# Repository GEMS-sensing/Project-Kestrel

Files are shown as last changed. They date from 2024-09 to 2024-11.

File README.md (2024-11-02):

<!-- [![DOI](https://zenodo.org/badge/678911830.svg)](https://zenodo.org/doi/10.5281/zenodo.13377368) -->

# Project-Kestrel
Core board for a Flight data logger, featuring interfaces to Talon boards ([SDI-12 Talon](https://github.com/GEMS-sensing/Talon-SDI12), [I2C Talon](https://github.com/GEMS-sensing/Talon-I2C), [Auxiliary Talon](https://github.com/GEMS-sensing/Talon-Auxiliary)) and external battery board ([Gonk](https://github.com/GEMS-sensing/Project-Gonk)). This is the core component of [Flight data logger](https://github.com/GEMS-sensing/DFM_-_Flight?tab=readme-ov-file).

# Repo Roadmap
#### [Documents](Documentation/) 

General document and image storage for repo and README

#### [Hardware](Hardware/)

Current board files (Eagle), Bill of Materials (BoM), and other design documents

#### [Production](Production/)

Contains the various Gerber and pick and place files required to have the Printed Circuit Boards (PCBs) manufactured or populated 

#### [Software](Software/)

The software associated with the piece of hardware, this is usually diagnostic software used for verifying or investigating the hardware

<!-- #### [Mechanical](Mechanical/)

Mechanical design files and assembly documents -->

<!-- #### [Testing](Testing/)

Scripts and results from the testing process and development process. Contains more detailed information about documented issues among other testing. 
 -->

## Overview
* **Type:** Logger
* **Interfaces:** Talon, Gonk
* **Release Version:** v1.9 - 2023/06/23

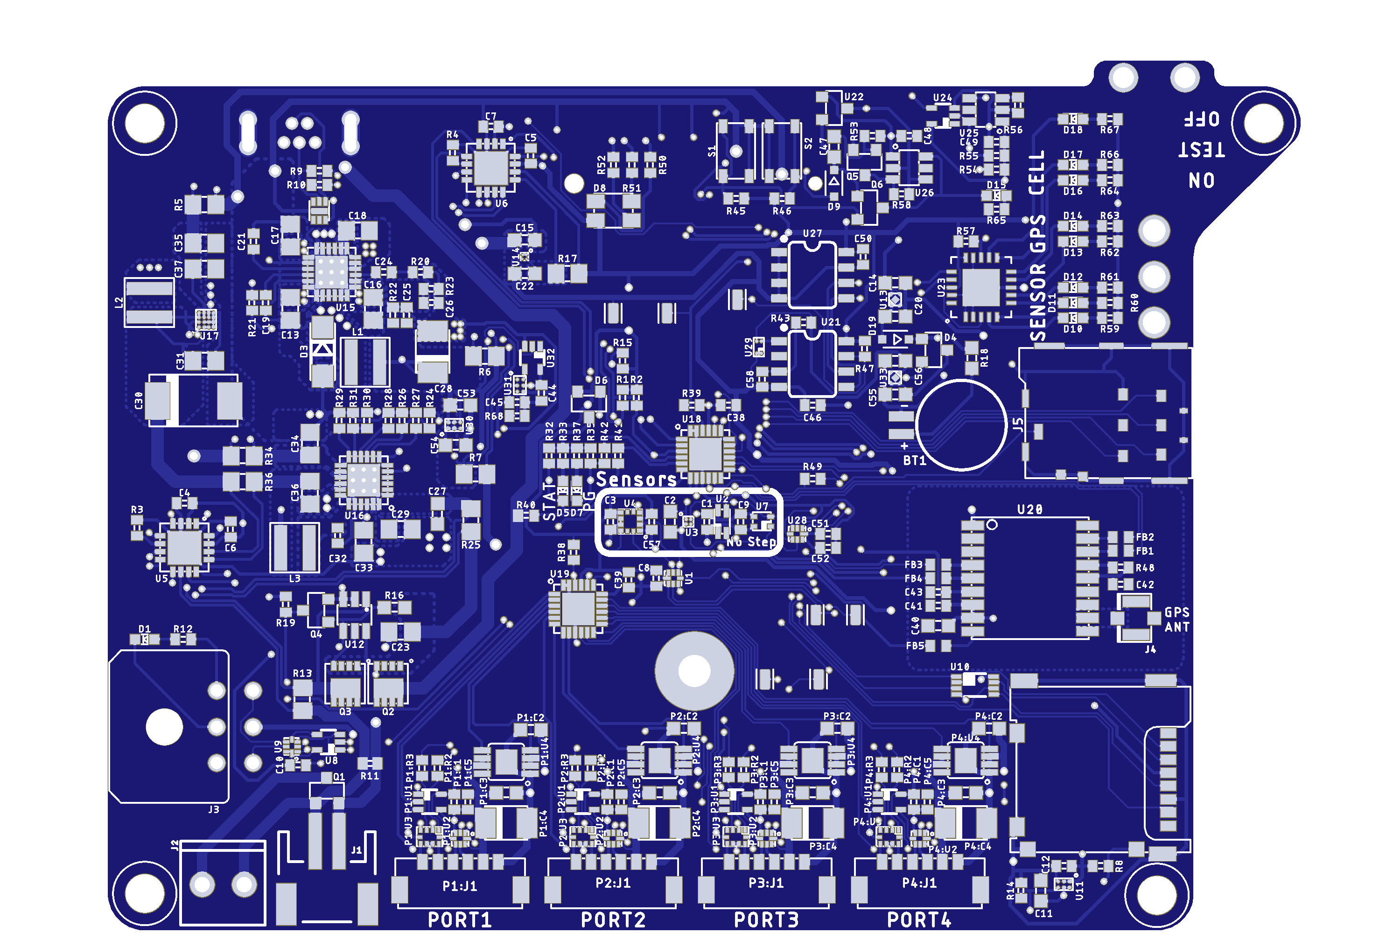
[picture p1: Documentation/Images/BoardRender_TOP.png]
PCB render image, top


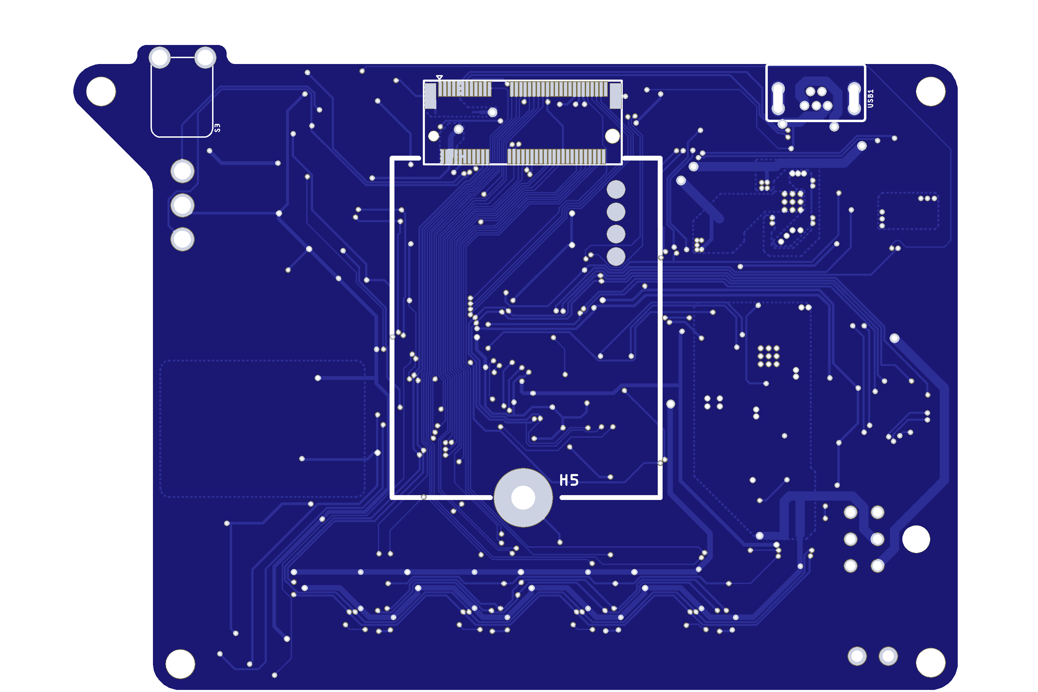
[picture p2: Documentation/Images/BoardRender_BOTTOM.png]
PCB render image, bottom


<!-- ![Haar v0.0 - Bottom](Documents/Images/Haar_0v0_Bottom_Cropped.jpg) -->

## Features
### On-Board
* Modular interfaces for Talon daughterboards (x4)
	* Isolated I2C interface
	* Individual power control and monitoring
	* Firmware selectable GPIO/UART interface
	* Polarized connector
* Battery board interface 
	* I2C interface for battery power reporting
	* Polarized connector
* Multi-charger input
	* Solar panel (6V) input
	* High power (>2A) input for fast charge in no solar situations
* [Particle BSoM](https://docs.particle.io/b-series/) M.2 interface
	* Interface for the highly flexible Particle BSoM module
* Micro USB interface 
	* Programming and charging
* Power switch
	* Complete disconnect 
	* Tri position to allow for 'ON'-'TESTING'-'OFF' modes
* LED status indicators 
* Non-Contact safe mode circuit 
	* Safe mode circuit controlled by Hall effect sensor to allow for triggering with magnet from outside logger box
* Multi-rail power system
	* Allow for independent control of subsystems, on-board and off-board
* On-board GPS Module with battery backup for improved hot start
* SD Card interface
* On-board sensing for self diagnostics
	* Voltage/current sensing (8 positions)
	* Temperature
	* Humidity
	* Accelerometer, 3 axis
	* Magnatometer, 3 axis
	* Ambient light, multi channel
* Interchangeable SIM card (future support)
* RTC with rechargeable battery backup
* FRAM storage for low power backhaul batching
* Long period WatchDog control to prevent critical lockups 

<!-- ### Interface
* I<sup>2</sup>C
* M12 circular connector  -->

<!-- <picture>
  <source media="(prefers-color-scheme: dark)" srcset="Documents/Pinout_LIGHT.png">
  <img alt="Haar Connector Pinout" src="Documents/Pinout.png">
</picture> -->

<!-- ## Specifications
* **Voltage - Supply:** 3.3V
* **Voltage - Logic:** 3.3V
* **Input Current (Avg, 1s period): 30.95&mu;A @ 3.3V**
* **Input Current (Avg, 5s period): 107.43&mu;A @ 3.3V**
* **Input Current (Max): 0.45mA @ 3.3V**

#### Sensor
**Temperature** [^1]
* Range: -40 ~ 125°C 
* Accuracy: &plusmn; 0.2°C
* Repeatability: &plusmn; 0.04°C

**Pressure** [^2]
* Range: 300 ~ 1200 hPa  
* Accuracy: &plusmn; 1 hPa
* Repeatability: &plusmn; 0.06 hPa

**Humidity** [^1]
* Range: 0 ~ 100%
* Accuracy: &plusmn; 2%
* Repeatability: 0.08%

[^1]: [SHT31 Datasheet](https://sensirion.com/media/documents/213E6A3B/63A5A569/Datasheet_SHT3x_DIS.pdf)
[^2]: [DPS368 Datasheet](https://www.infineon.com/dgdl/Infineon-DPS368-DS-v01_00-EN.pdf?fileId=5546d46269e1c019016a0c45105d4b40) -->

<!-- ## Version History

`v0.0` - Initial primal version with screw terminal

`v0.1` - Initial 'hard mount' version, using M12 connector

`v1.0` - Removed pullup select[^3], added logic level buffer and voltage reg on input

`v1.1` - Moved via away from connector pads to prevent bridging when soldering 

`v2.0` - Fixed issue with address select jumper[^3] -->

<!-- ## Jumper Settings 

> [!IMPORTANT]
> Jumper settings valid for version `v2.0` and beyond[^3]

[^3]: See Errata

**Configuration Jumpers**
| Jumper | Purpose | Open | Closed | Default | 
| --- | --- | --- | --- | ----- |
| `JP1` | I<sup>2</sup>C Address Select | Base Address<sup>&dagger;</sup> | Alt Address<sup>&Dagger;</sup> | Open |

&dagger; SHT31 = `0x44`, DPS368 = `0x76`

&Dagger; SHT31 = `0x44`, DPS368 = `0x77`

 -->

## Version History

v1.7 updates:
- Connected DONE line on U26 to ensure consistent trip (prevent factory reset while using hall effect control)
- Changed label for 'STAT' led in upper right corner to 'SYS', this was done to reflect the current usage of the indicator and to eliminate confusion between this indicator and the indicator lamp for the battery charge (also labeled 'STAT')
- Switched amber LEDs to yellow

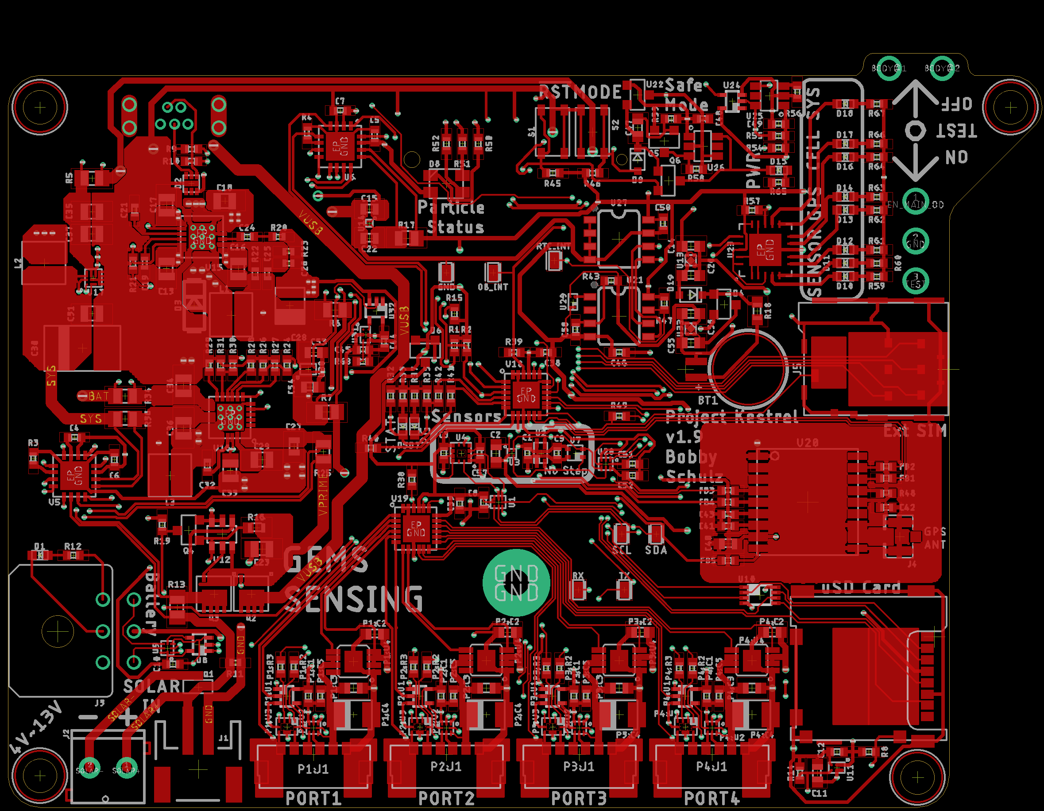
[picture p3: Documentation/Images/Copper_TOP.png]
PCB trace CAD image, top


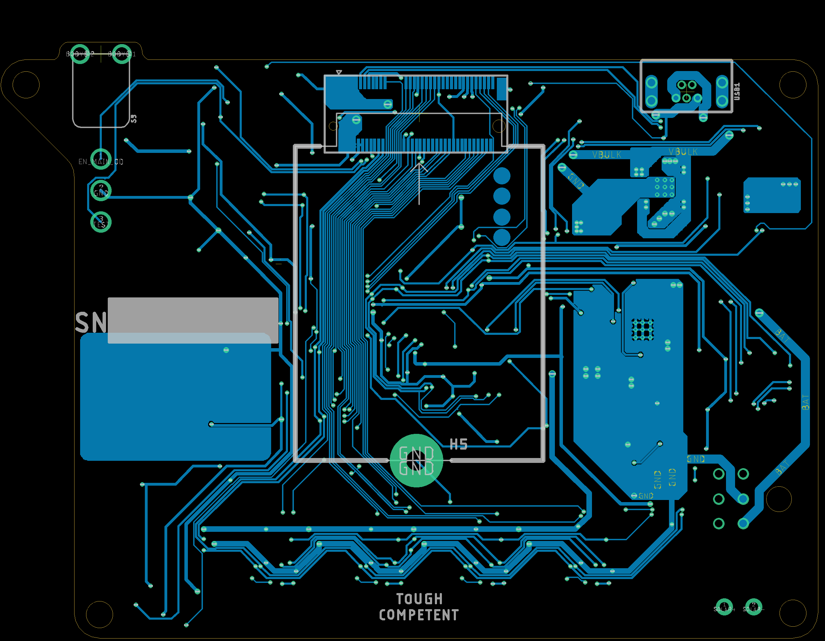
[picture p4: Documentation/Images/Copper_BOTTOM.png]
PCB trace CAD, bottom


## Known Issues/Errata

#### Solder Jumper Stencil

**Version Affected:** All

**Issue:** Solar input does not support very low impedance sources (e.g. lead acid battery) - see details in issue [#20](https://github.com/GEMS-sensing/Project-Kestrel/issues/20)

**Workaround:** 

* Avoid use of low impedance batteries for input
* Include series impedance to prevent current spikes (not desirable)
* Perform board patch described in issue [#20](https://github.com/GEMS-sensing/Project-Kestrel/issues/20)

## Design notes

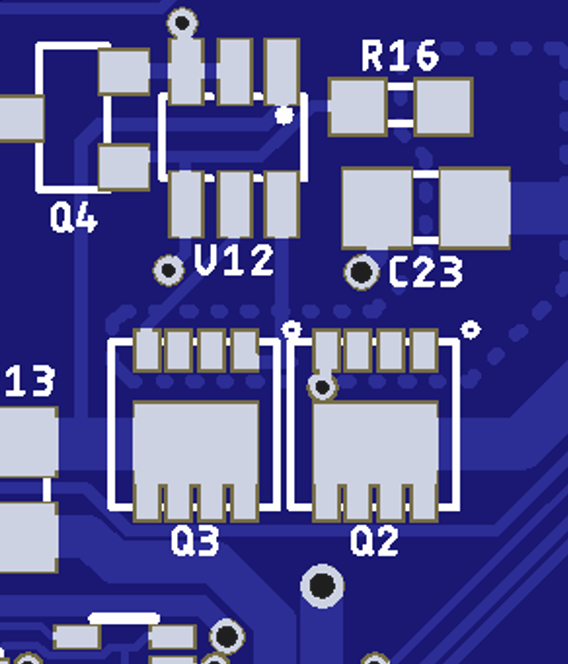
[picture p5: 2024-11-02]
Documentation/Images/Q2Subset.png

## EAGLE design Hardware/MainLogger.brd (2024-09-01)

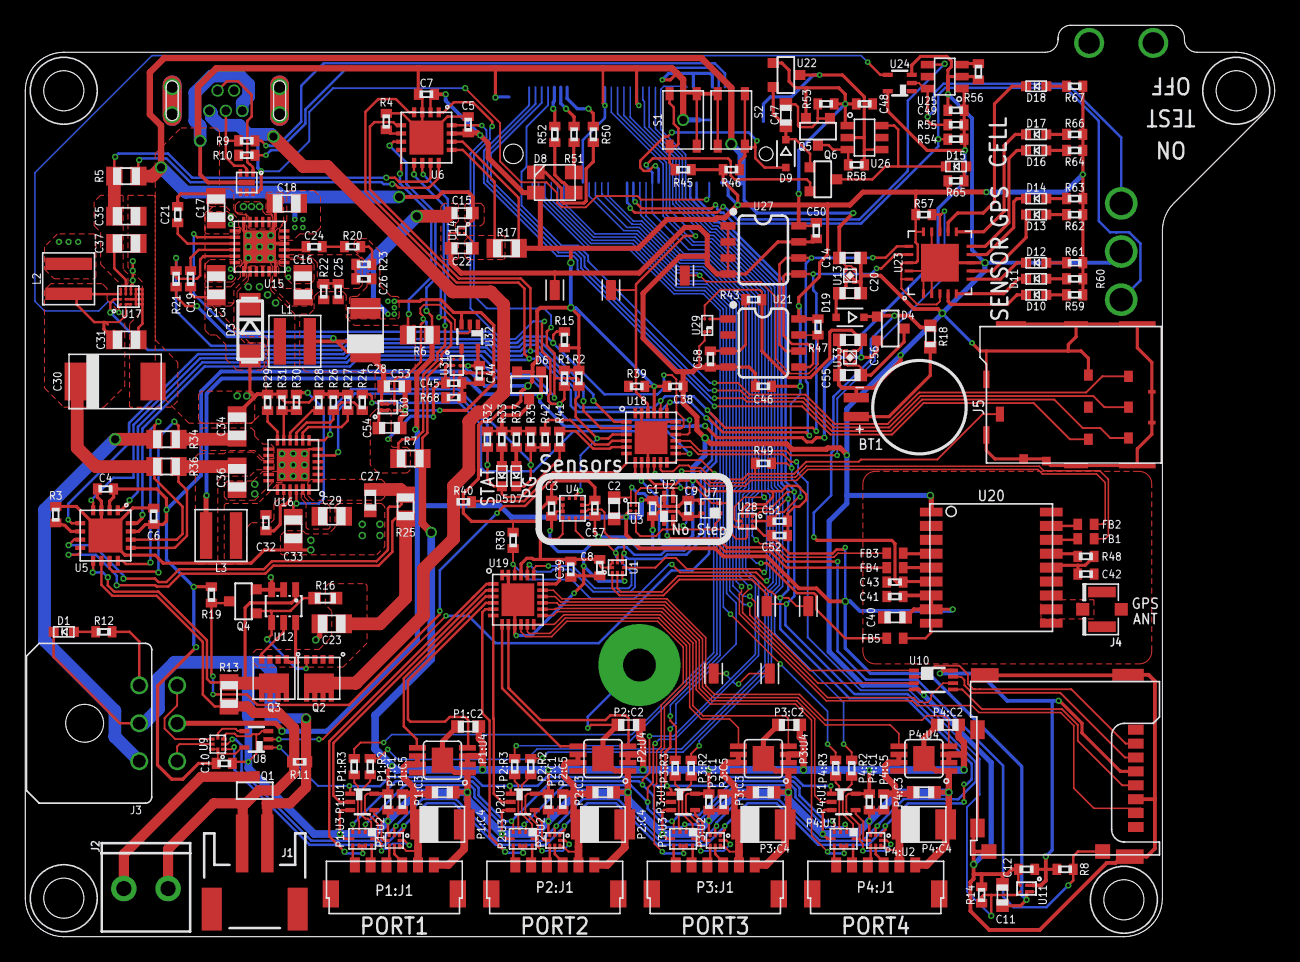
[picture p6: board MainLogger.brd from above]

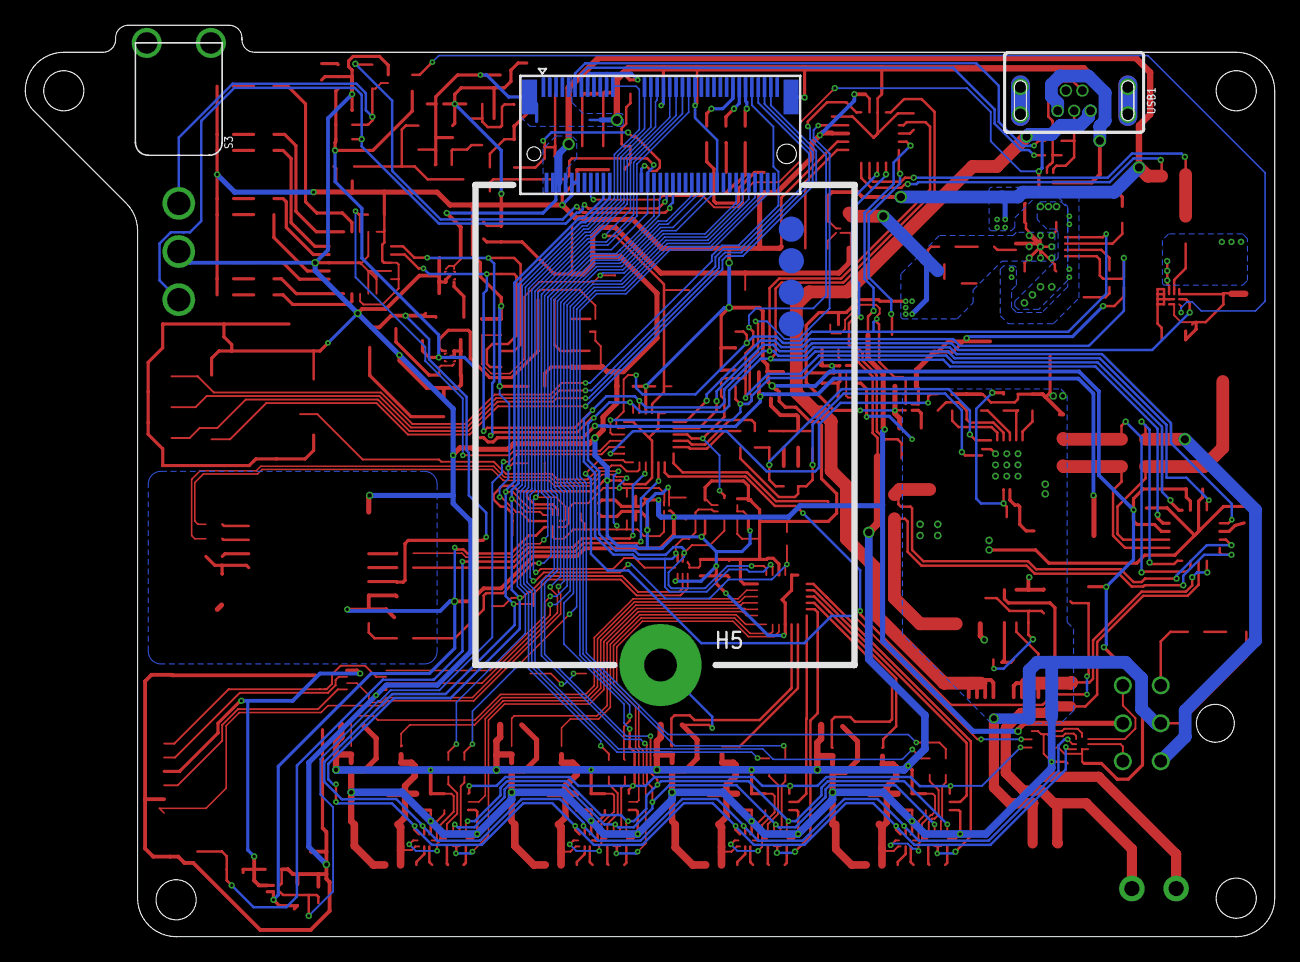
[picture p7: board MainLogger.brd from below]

Board: 2 copper layers, 98.9 x 72.1 mm, 262 parts (3 on the bottom side), 202 nets.

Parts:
$3_190_$_2021-12-10_02-09-55: B_SERIES_M.2EKEY_3042; PARTICLE_M.2EKEY
BT1: BATTERY_COINML621; ML621S
C1, C3, C4, C5, C6, C7, C8, C9, C10, C12, C38, C39, C41, C43, C44, C45, C46, C48, C49, C50, C51, C52, C57: 0.1uF; C0402
C2: 2.2uF; C0603
C11, C14, C15, C20, C22, C27, C40, C47, C53, C54, C55, C56: 1uF; C0603
C13, C16, C17, C18, C34: 22uF; C0805
C19: 1nF; C0402
C21, C25: 10nF; C0402
C23, C29, C35, C36, C37: 10uF; C0805
C24: 39pF; C0402
C26, C58: 100pF; C0402
C28: 100uF; C1411_TANT
C30: 220uF; C2917
C31: 1.5uF; C0805
C32: 47nF; C0402
C33: 4.7uF; C0805
C42: 47pF; C0402
D1, D12, D18: LEDRED0603; LED_0603
D2: RCLAMP3654; DFN_6_1.6X1.6
D3: CDBA3100; DO214AC
D4: BAT54C; SOT23-3
D5, D10, D13, D15, D16: LEDGREEN0603; LED_0603
D6: SOT23-3
D7, D11, D14, D17: LEDYELLOW0603; LED_0603
D8: CLVBA-FKA
D9, D19: BAT54WS; SOD323-R
FB1, FB2, FB3, FB4, FB5: R0402
H1, H2, H3, H4: 4_40
J1: JST-2-SMD
J2: SCREWTERMINAL-3.5MM-2_ROUND_RESTRICT
J3: GEMS_POWER_PLUGINPUT_RT; 2X3_MICROFIT_RT
J4: U.FL
J5: SIM_CDNANO_SF72; SIM_SF72
L1, L3: 1uH; WE-MAIA(4.1X4.1)
L2: 0.47uH; WE-MAPI(4.1X4.1)
P1:C1, P1:C5, P2:C1, P2:C5, P3:C1, P3:C5, P4:C1, P4:C5: 0.1uF; C0402
P1:C2, P2:C2, P3:C2, P4:C2: 2.2uF; C0603
P1:C3, P2:C3, P3:C3, P4:C3: 1uF; C0603
P1:C4, P2:C4, P3:C4, P4:C4: 100uF; C1411_TANT
P1:J1, P2:J1, P3:J1, P4:J1: CONN_TALON_LOGGER; 1X06_MICROLOCKPLUS_RT
P1:R2, P1:R3, P2:R2, P2:R3, P3:R2, P3:R3, P4:R2, P4:R3: 1k; R0402
P1:U1, P2:U1, P3:U1, P4:U1: SN74AUP1G08DCK; DCK_R-PDSO-G5
P1:U2, P2:U2, P3:U2, P4:U2: FXMAR2102UMLP; UQFN-8_1.4X1.2
P1:U3, P2:U3, P3:U3, P4:U3: FSA2258; MICROPAK_10
P1:U4, P2:U4, P3:U4, P4:U4: AP2411; MSOP_8EP
Q1, Q4: DMG3404; SOT23-3
Q2, Q3: MOSFET_PCH-DMP3036SFG; POWERDI3333-8
Q5, Q6: NX2301P; SOT23-3
R1, R2, R11, R19, R26, R32, R35, R40, R41, R42, R54, R55: 1M; R0402
R3, R20: 20k; R0402
R4: 2k; R0402
R5, R13, R25, R34, R36: 2m; R0805
R6, R7, R17: 10m; R0805
R8, R14, R15, R21, R30, R31, R38, R39, R47, R49, R53, R57: 100k; R0402
R9, R10: 27R; R0402
R12, R43: 1k; R0402
R16: 470k; R0603
R18: 750R; R0603
R22, R29, R33, R45, R46, R65: 10k; R0402
R23, R37: 2.7k; R0402
R24: 0R; R0402
R27, R28, R59, R60, R61, R62, R63, R64, R66, R67: 220R; R0402
R48: 10; R0402
R50, R51, R52, R68: 5.6k; R0402
R56: 130k; R0402
R58: 11k; R0402
S1, S2: BUTTON4.2X3.2; SWITCH_4.2X3.2
S3: SPDT7103K2CWAV2; 7103K2CWAV2
SD1: MICROSDMOLEX_503182; MICROSD_MOLEX_5031821852
TP1, TP2, TP5, TP6, TP7, TP8, TP9: TESTPOINT_DNP_RCU; TESTPOINT_0603
U1, U9, U28: FXMAR2102UMLP; UQFN-8_1.4X1.2
U2: VEML3328; VEML6075
U3: MMC5633; BGA_4
U4: BMA456; LGA-12_2X2
U5, U6: PAC1934QFN; QFN16
U7: SHT40; SHT4X
U8: SN74AUP1G08DCK; DCK_R-PDSO-G5
U10: SN74AUP3G34DCU; DCU_(R-PDSO-G8)
U11, U30: TCK111G; WCSP_6
U12: LTC4412S6; SOT23-6L
U13: TPS7A0331PDQ; X2SON
U14: LP59073.3VYKE; YKE0004
U15: MIC22602; QFN24_POWER
U16: BQ25616; QFN24_POWER
U17: TPS61282D; YFP0016
U18, U19: PCAL9535AQFN; QFN24
U20: MAX-M8W; MAX-M8
U21: MCP79412SOIC; SO08
U22: HALL_EFFECT_SI7201; SOT23-3
U23: PCA9634QFN; QFN20_5X5
U24: SN74LVC1G17DCK; DCK_R-PDSO-G5
U25, U26: TPL5010DDC; DDC_R-PDSO-G6
U27: MB85RC; SO08
U29: SIT1552; LD-4
U31: FPF2195BUCX; WCSP_6
U32: DCK_R-PDSO-G5
U33: TPS7A0218PDQ; X2SON
USB1: USB_MICROMUSB-K152; MUSB-K152-30

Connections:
3V3_AUX: C1.1, C2.1, C9.1, C11.1, C40.1, C41.1, C52.1, J3.5, R6.1, U2.4, U3.B1, U6.7, U7.3, U11.A2, U11.B2, U20.7, U20.8, U28.8
3V3_AUX_EN: R15.1, U15.2, U18.17, U30.C2, U32.2
3V3_AUX_PG: R21.1, U15.5, U18.1
3V3_BULK+: C25.1, C28.ANODE, C53.1, L1.P$2, R6.2, R21.2, R22.2, U6.8, U30.A2, U30.B2
3V3_CORE: $3_190_$_2021-12-10_02-09-55.10, $3_190_$_2021-12-10_02-09-55.12, C3.1, C4.1, C5.1, C6.1, C7.1, C8.1, C10.1, C38.1, C39.1, C44.1, C46.1, C48.1, C50.1, C51.1, C57.1, D6.2, D8.2, Q5.2, R1.2, R2.2, R15.2, R17.2, R19.2, R38.2, R39.2, R45.2, R46.2, R47.2, R49.2, R53.2, R57.2, R59.2, R60.2, R61.2, R62.2, R63.2, R64.2, R65.2, R66.2, R67.2, U1.1, U1.8, U4.3, U4.7, U4.10, U5.2, U5.15, U6.2, U6.14, U6.15, U8.5, U9.1, U9.8, U18.21, U19.18, U19.21, U21.8, U22.1, U23.3, U23.15, U23.18, U23.20, U26.1, U27.8, U28.1, U31.B2, U32.5
3V3_CORE+: C22.1, R17.1, U6.13, U14.A2
3V3_SD: C12.1, R8.2, SD1.4, U10.8, U11.A1, U11.B1
3V3_SD_EN: R14.2, U11.C2, U18.14
3V3_TALON: P1:C1.1, P1:C2.1, P1:U1.5, P1:U2.1, P1:U3.10, P1:U4.2, P1:U4.3, P2:C1.1, P2:C2.1, P2:U1.5, P2:U2.1, P2:U3.10, P2:U4.2, P2:U4.3, P3:C1.1, P3:C2.1, P3:U1.5, P3:U2.1, P3:U3.10, P3:U4.2, P3:U4.3, P4:C1.1, P4:C2.1, P4:U1.5, P4:U2.1, P4:U3.10, P4:U4.2, P4:U4.3, R7.2, U6.9
3V3_TALON+: C45.1, C54.1, R7.1, U6.10, U30.A1, U30.B1, U31.B1
!CE: R24.1, U18.13
!CHG_PG: D7.CATHODE, R35.1, R42.2, U16.7
!MODE: $3_190_$_2021-12-10_02-09-55.32, D9.A, R46.1, S2.1, S2.2
!RESET: $3_190_$_2021-12-10_02-09-55.34, FB5.2, Q6.2, R45.1, S1.1, S1.2
!TALON1_FAULT: P1:U4.5, U19.3
!TALON2_FAULT: P2:U4.5, U19.7
!TALON3_FAULT: P3:U4.5, U19.12
!TALON4_FAULT: P4:U4.5, U19.16
BAT: J3.1, R34.2, U5.12
BAT_CHG: C34.1, R34.1, U5.11, U16.13, U16.14
BCKP_GPS: C43.1, D4.1, D19.C, R18.1, U20.6
BCKP_GPS_REG: C20.1, D19.A, U13.1
BCKP_PRIME: C55.1, D4.3, U33.3, U33.4
BCKP_RTC: C58.1, R43.2, U21.3
BTST: C32.2, U16.21
CHG_SOURCE: Q4.3, R19.1, U18.7
CHG_STAT: D5.CATHODE, R32.1, R41.2, U16.5
CLK_OSC: U21.1, U29.2
COMP: C24.1, U15.15
CSA_EN: R1.1, U5.16, U6.16, U18.16
D+: $3_190_$_2021-12-10_02-09-55.11, R9.1
D+_IN: D2.2, R9.2, USB1.3
D-: $3_190_$_2021-12-10_02-09-55.13, R10.1
D-_IN: D2.1, R10.2, USB1.2
DELAY: C21.1, U15.3
EN_MAIN: U17.A1, U24.4
EN_MAIN_OD: R55.2, S3.1, U24.2, U25.6
FAULT_BUS: D1.ANODE, R12.2
FB: C25.2, C26.1, R22.1, R23.2, U15.14
GND: $3_190_$_2021-12-10_02-09-55.1, $3_190_$_2021-12-10_02-09-55.3, $3_190_$_2021-12-10_02-09-55.5, $3_190_$_2021-12-10_02-09-55.7, $3_190_$_2021-12-10_02-09-55.9, $3_190_$_2021-12-10_02-09-55.15, $3_190_$_2021-12-10_02-09-55.21, $3_190_$_2021-12-10_02-09-55.39, $3_190_$_2021-12-10_02-09-55.49, $3_190_$_2021-12-10_02-09-55.56, $3_190_$_2021-12-10_02-09-55.76, $3_190_$_2021-12-10_02-09-55.77, $3_190_$_2021-12-10_02-09-55.GND, BT1.-, C1.2, C2.2, C3.2, C4.2, C5.2, C6.2, C7.2, C8.2, C9.2, C10.2, C11.2, C12.2, C13.2, C14.2, C15.2, C16.2, C17.2, C18.2, C19.2, C20.2, C21.2, C22.2, C23.2, C26.2, C27.2, C28.CATHODE, C29.2, C30.-, C31.2, C33.2, C34.2, C35.2, C36.2, C37.2, C38.2, C39.2, C40.2, C41.2, C42.2, C43.2, C44.2, C45.2, C46.2, C48.2, C49.2, C50.2, C51.2, C52.2, C53.2, C54.2, C55.2, C56.2, C57.2, C58.2, D1.CATHODE, D2.EP, D3.A, J1.1, J3.2, J4.1, J4.2, J5.5, J5.CSW, J5.GND@1, J5.GND@2, J5.GND@3, J5.GND@4, J5.GND@5, J5.GND@6, J5.GND@7, J5.GND@8, J5.GND@9, J5.GND@10, P1:C1.2, P1:C2.2, P1:C3.2, P1:C4.CATHODE, P1:C5.2, P1:J1.1, P1:U1.3, P1:U2.4, P1:U3.5, P1:U4.1, P1:U4.EP, P2:C1.2, P2:C2.2, P2:C3.2, P2:C4.CATHODE, P2:C5.2, P2:J1.1, P2:U1.3, P2:U2.4, P2:U3.5, P2:U4.1, P2:U4.EP, P3:C1.2, P3:C2.2, P3:C3.2, P3:C4.CATHODE, P3:C5.2, P3:J1.1, P3:U1.3, P3:U2.4, P3:U3.5, P3:U4.1, P3:U4.EP, P4:C1.2, P4:C2.2, P4:C3.2, P4:C4.CATHODE, P4:C5.2, P4:J1.1, P4:U1.3, P4:U2.4, P4:U3.5, P4:U4.1, P4:U4.EP, Q1.2, Q4.2, R3.1, R4.1, R11.1, R14.1, R20.1, R23.1, R26.1, R27.1, R28.1, R29.2, R31.1, R56.1, R58.1, R68.1, S1.3, S1.4, S2.3, S2.4, S3.2, SD1.6, SD1.BODY@1, SD1.BODY@2, SD1.BODY@3, SD1.BODY@4, SD1.BODY@5, SD1.SW1, TP1.1, U1.4, U2.1, U3.A1, U4.1, U4.8, U4.9, U5.3, U5.EP, U6.3, U6.EP, U7.4, U8.3, U9.4, U10.4, U11.C1, U12.2, U12.3, U13.2, U13.EP, U14.B2, U15.7, U15.12, U15.16, U15.19, U15.24, U15.EP, U15.EP@1, U15.EP@2, U15.EP@3, U15.EP@4, U15.EP@5, U15.EP@6, U15.EP@7, U15.EP@8, U15.EP@9, U16.6, U16.17, U16.18, U16.EP, U16.EP@1, U16.EP@2, U16.EP@3, U16.EP@4, U16.EP@5, U16.EP@6, U16.EP@7, U16.EP@8, U16.EP@9, U17.B2, U17.C2, U17.D1, U17.D2, U17.D3, U17.D4, U18.9, U18.18, U18.23, U18.24, U18.EP, U19.9, U19.23, U19.24, U19.EP, U20.1, U20.10, U20.12, U21.4, U22.3, U23.1, U23.2, U23.8, U23.14, U23.19, U23.EP, U24.3, U25.2, U26.2, U26.4, U27.1, U27.2, U27.3, U27.4, U27.7, U28.4, U29.1, U29.4, U30.C1, U31.C2, U32.3, U33.2, U33.EP, USB1.5
GPS_ANT: J4.FEED, U20.11
GPS_INT: FB4.1, U18.8
GPS_INT_CLEAN: FB4.2, U20.5
I2C_EXT_EN: U8.2, U18.12
I2C_EXT_EN_OUT: U8.4, U9.5
I2C_GLOBAL_EN: $3_190_$_2021-12-10_02-09-55.64, P1:U1.1, P2:U1.1, P3:U1.1, P4:U1.1, U8.1
I2C_OB_EN: $3_190_$_2021-12-10_02-09-55.45, U1.5, U28.5
ICHG: R28.2, U16.10
ILIM: R27.2, U16.8
LED_BLUE: $3_190_$_2021-12-10_02-09-55.65, R52.2
LED_EN: R57.1, U18.15, U23.13
LED_GREEN: $3_190_$_2021-12-10_02-09-55.63, R51.2
LED_RED: $3_190_$_2021-12-10_02-09-55.61, R50.2
MISO: $3_190_$_2021-12-10_02-09-55.50, SD1.7
MOSI: $3_190_$_2021-12-10_02-09-55.52, U10.1
MOSI_BUF: SD1.3, U10.7
unnamed: R3.2, U5.6
unnamed: Q3.4, U12.5
unnamed: R41.1, U18.5
unnamed: BT1.+, R18.2
unnamed: R40.1, U18.6
unnamed: R42.1, U18.4
unnamed: R24.2, R26.2, U16.9
unnamed: C47.1, D9.C, Q6.1, U22.2
unnamed: D15.CATHODE, Q6.3, U26.6
unnamed: C47.2, Q5.1, R53.1
unnamed: D15.ANODE, R65.1
unnamed: R4.2, U6.6
unnamed: D7.ANODE, R37.1
unnamed: R68.2, U31.C1
unnamed: D5.ANODE, R33.1
unnamed: D8.3, R52.1
unnamed: D8.4, R51.1
unnamed: D8.1, R50.1
unnamed: FB5.1, U20.9
unnamed: J3.3, R12.1
unnamed: U31.A2, U32.4
unnamed: R56.2, U25.3
unnamed: Q5.3, R58.2, U26.3
unnamed: C24.2, R20.2
unnamed: D10.CATHODE, U23.4
unnamed: D11.CATHODE, U23.5
unnamed: D12.CATHODE, U23.6
unnamed: D13.CATHODE, U23.7
unnamed: D14.CATHODE, U23.9
unnamed: D16.CATHODE, U23.10
unnamed: D17.CATHODE, U23.11
unnamed: D18.CATHODE, U23.12
unnamed: D10.ANODE, R59.1
unnamed: D11.ANODE, R60.1
unnamed: D12.ANODE, R61.1
unnamed: D13.ANODE, R62.1
unnamed: D14.ANODE, R63.1
unnamed: D16.ANODE, R64.1
unnamed: D17.ANODE, R66.1
unnamed: D18.ANODE, R67.1
OB_INT: $3_190_$_2021-12-10_02-09-55.43, R39.1, TP7.1, U18.22
P1:3V3_TALON: P1:C3.1, P1:C4.ANODE, P1:C5.1, P1:J1.2, P1:U2.8, P1:U4.6, P1:U4.7
P1:I2C_EN_LOCAL: P1:U1.4, P1:U2.5
P1:N$1: P1:R2.1, P1:U3.1
P1:N$2: P1:R3.1, P1:U3.3
P1:RX_TALON: P1:J1.6, P1:U3.6
P1:SCL_EXT: P1:J1.4, P1:U2.6
P1:SDA_EXT: P1:J1.3, P1:U2.7
P1:TX_TALON: P1:J1.5, P1:U3.9
P2:3V3_TALON: P2:C3.1, P2:C4.ANODE, P2:C5.1, P2:J1.2, P2:U2.8, P2:U4.6, P2:U4.7
P2:I2C_EN_LOCAL: P2:U1.4, P2:U2.5
P2:N$1: P2:R2.1, P2:U3.1
P2:N$2: P2:R3.1, P2:U3.3
P2:RX_TALON: P2:J1.6, P2:U3.6
P2:SCL_EXT: P2:J1.4, P2:U2.6
P2:SDA_EXT: P2:J1.3, P2:U2.7
P2:TX_TALON: P2:J1.5, P2:U3.9
P3:3V3_TALON: P3:C3.1, P3:C4.ANODE, P3:C5.1, P3:J1.2, P3:U2.8, P3:U4.6, P3:U4.7
P3:I2C_EN_LOCAL: P3:U1.4, P3:U2.5
P3:N$1: P3:R2.1, P3:U3.1
P3:N$2: P3:R3.1, P3:U3.3
P3:RX_TALON: P3:J1.6, P3:U3.6
P3:SCL_EXT: P3:J1.4, P3:U2.6
P3:SDA_EXT: P3:J1.3, P3:U2.7
P3:TX_TALON: P3:J1.5, P3:U3.9
P4:3V3_TALON: P4:C3.1, P4:C4.ANODE, P4:C5.1, P4:J1.2, P4:U2.8, P4:U4.6, P4:U4.7
P4:I2C_EN_LOCAL: P4:U1.4, P4:U2.5
P4:N$1: P4:R2.1, P4:U3.1
P4:N$2: P4:R3.1, P4:U3.3
P4:RX_TALON: P4:J1.6, P4:U3.6
P4:SCL_EXT: P4:J1.4, P4:U2.6
P4:SDA_EXT: P4:J1.3, P4:U2.7
P4:TX_TALON: P4:J1.5, P4:U3.9
PMID: C29.1, U16.23
RC: C19.1, U15.4
REGN: C33.1, R30.2, U16.22
RTC_INT: $3_190_$_2021-12-10_02-09-55.62, R47.1, TP2.1, U21.7
RX: $3_190_$_2021-12-10_02-09-55.38, P1:U3.4, P2:U3.4, P3:U3.4, P4:U3.4, TP9.1
SCK: $3_190_$_2021-12-10_02-09-55.54, U10.3
SCK_BUF: SD1.5, U10.5
SCL: $3_190_$_2021-12-10_02-09-55.20, P1:U2.3, P2:U2.3, P3:U2.3, P4:U2.3, TP6.1, U1.2, U9.3, U28.3
SCL_AUX: FB2.1, U2.3, U3.A2, U7.2, U28.6
SCL_EXT: J3.6, U9.6
SCL_GPS: FB2.2, U20.17
SCL_OB: U1.7, U4.12, U5.4, U6.4, U18.19, U19.19, U21.6, U23.16, U27.6
SDA: $3_190_$_2021-12-10_02-09-55.22, P1:U2.2, P2:U2.2, P3:U2.2, P4:U2.2, TP5.1, U1.3, U9.2, U28.2
SDA_AUX: FB1.1, U2.2, U3.B2, U7.1, U28.7
SDA_EXT: J3.4, U9.7
SDA_GPS: FB1.2, U20.16
SDA_OB: U1.6, U4.2, U5.5, U6.5, U18.20, U19.20, U21.5, U23.17, U27.5
SD_CD: R8.1, SD1.SW2, U18.10
SD_CS: $3_190_$_2021-12-10_02-09-55.48, U10.6
SD_CS_BUF: SD1.2, U10.2
SENSOR_INT: R2.1, U4.5, U5.1, U6.1, U18.3
SIM_CD: J5.DSW, R49.1, U18.11
SIM_CLK: $3_190_$_2021-12-10_02-09-55.71, J5.3
SIM_DATA: $3_190_$_2021-12-10_02-09-55.73, J5.7
SIM_RST: $3_190_$_2021-12-10_02-09-55.69, J5.2
SIM_VCC: $3_190_$_2021-12-10_02-09-55.67, J5.1
SOLAR+: J1.2, J2.1, Q1.1, R11.2, R13.1, U5.10
SOLAR-: J2.2, Q1.3
STAT_CORE: D6.3, R32.2, R33.2, R35.2, R37.2
ST_CORE: Q2.4, Q4.1, R16.1, U12.4
SW: C32.1, L3.P$1, U16.19, U16.20
SW1: D3.C, L1.P$1, U15.8, U15.9, U15.10, U15.11, U15.20, U15.21, U15.22, U15.23
SW2: L2.P$2, U17.C3, U17.C4
SYS: C30.+, C31.1, L2.P$1, R36.2, U5.14, U17.A3, U17.A4, U17.B1, U17.C1
SYSCORE: C36.1, C49.1, D4.2, D6.1, L3.P$2, R36.1, R54.1, R55.1, U5.13, U16.15, U16.16, U24.5, U25.1
TALON1_EN: P1:U4.4, U19.4
TALON1_GPIOA: $3_190_$_2021-12-10_02-09-55.37, P1:R2.2
TALON1_GPIOB: $3_190_$_2021-12-10_02-09-55.72, P1:R3.2
TALON1_I2C_EN: P1:U1.2, U19.2
TALON1_SEL: P1:U3.7, P1:U3.8, U19.1
TALON2_EN: P2:U4.4, U19.8
TALON2_GPIOA: $3_190_$_2021-12-10_02-09-55.35, P2:R2.2
TALON2_GPIOB: $3_190_$_2021-12-10_02-09-55.70, P2:R3.2
TALON2_I2C_EN: P2:U1.2, U19.6
TALON2_SEL: P2:U3.7, P2:U3.8, U19.5
TALON3_EN: P3:U4.4, U19.13
TALON3_GPIOA: $3_190_$_2021-12-10_02-09-55.33, P3:R2.2
TALON3_GPIOB: $3_190_$_2021-12-10_02-09-55.68, P3:R3.2
TALON3_I2C_EN: P3:U1.2, U19.11
TALON3_SEL: P3:U3.7, P3:U3.8, U19.10
TALON4_EN: P4:U4.4, U19.17
TALON4_GPIOA: $3_190_$_2021-12-10_02-09-55.23, P4:R2.2
TALON4_GPIOB: $3_190_$_2021-12-10_02-09-55.66, P4:R3.2
TALON4_I2C_EN: P4:U1.2, U19.15
TALON4_SEL: P4:U3.7, P4:U3.8, U19.14
TALON_INT: $3_190_$_2021-12-10_02-09-55.41, R38.1, U19.22
TEST: $3_190_$_2021-12-10_02-09-55.40, R54.2, S3.3
TIMEPULSE: $3_190_$_2021-12-10_02-09-55.47, FB3.1
TIMEPULSE_CLEAN: FB3.2, U20.4
TS: R30.1, R31.2, U16.11
TX: $3_190_$_2021-12-10_02-09-55.36, P1:U3.2, P2:U3.2, P3:U3.2, P4:U3.2, TP8.1
VBULK: $3_190_$_2021-12-10_02-09-55.2, $3_190_$_2021-12-10_02-09-55.4, $3_190_$_2021-12-10_02-09-55.6, $3_190_$_2021-12-10_02-09-55.8, C13.1, C14.1, C15.1, C16.1, C17.1, C18.1, R5.1, U6.12, U13.3, U13.4, U14.A1, U14.B1, U15.1, U15.6, U15.13, U15.17, U15.18
VBULK+: C35.1, C37.1, R5.2, U6.11, U17.B3, U17.B4
VBULK_PG: U17.A2, U18.2
VBUS: C27.1, R25.2, U5.7, U16.1, U16.24
VCC_RF: C42.1, R48.1, U20.14
VDD_CLK: C56.1, R43.1, U29.3, U33.1
VPRIME: C23.1, Q2.1, Q2.2, Q2.3, Q3.1, Q3.2, Q3.3, R16.2, R25.1, U5.8, U12.6
VSET: R29.1, U16.12
VSOLAR: Q3.EP@1, Q3.EP@2, Q3.EP@3, Q3.EP@4, Q3.EP@5, R13.2, U5.9, U12.1
VUSB: $3_190_$_2021-12-10_02-09-55.16, D2.6, Q2.EP@1, Q2.EP@2, Q2.EP@3, Q2.EP@4, Q2.EP@5, R40.2, USB1.1
V_ANT: R48.2, U20.15
WDT_DONE: $3_190_$_2021-12-10_02-09-55.42, U25.4

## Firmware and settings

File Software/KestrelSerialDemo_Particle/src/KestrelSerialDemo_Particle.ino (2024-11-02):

// #include <Wire.h>
 // #include "Adafruit_MCP23008.h"
// #include <Adafruit_MCP23X17.h>
// #include <MCP2301x.h>
#include <Arduino.h>
#include <Particle.h>
#include "dct.h"
#include <MCP23018.h>
#include <PCAL9535A.h>
#include <arduino_bma456.h>

// #define NUM_MCP2301x_ICs   1

// const uint8_t I2C_GLOBAL_EN = 0; //FIX!

namespace Pins { //Use for B402
	constexpr uint16_t WD_HOLD  = D2;
	// constexpr uint16_t EXT_EN   = 13;
	// constexpr uint16_t SD_EN    = 1;
	constexpr uint16_t SD_CS    = D8;
	// constexpr uint16_t SD_CD    = 18;
	// constexpr uint16_t SDA_CTRL = 5;
	// constexpr uint16_t TIP      = 18;
	// constexpr uint16_t GPIOXA 	= 17;
	constexpr uint16_t Clock_INT 	= D22;
	// constexpr uint16_t Port1D 	= 11;
	// constexpr uint16_t Port2D 	= 10;
	// constexpr uint16_t Port3D  	= 9;
	// constexpr uint16_t Port1A 	= A2;
	// constexpr uint16_t Port2A 	= A1;
	// constexpr uint16_t Port3A 	= A0;
	constexpr uint16_t TALON1_GPIOA = A3;
	constexpr uint16_t TALON1_GPIOB = D7;
	constexpr uint16_t TALON2_GPIOA = A2;
	constexpr uint16_t TALON2_GPIOB = D6;
	constexpr uint16_t TALON3_GPIOA = A1;
	constexpr uint16_t TALON3_GPIOB = D5;
	constexpr uint16_t I2C_GLOBAL_EN = D23; //FIX!
	constexpr uint16_t I2C_OB_EN = A6; //FIX!
}

namespace PinsIO { //For Kestrel v1.1
	constexpr uint16_t VUSB = 5;
}

namespace PinsIOAlpha {
	constexpr uint16_t I2C_EXT_EN = 10;
	constexpr uint16_t SD_CD = 8;
	constexpr uint16_t SD_EN = 12;
	constexpr uint16_t AUX_EN = 15;
	constexpr uint16_t CE = 11;
}

namespace PinsIOBeta { //For Kestrel v1.1
	constexpr uint16_t SEL1 = 0;
	constexpr uint16_t SEL2 = 4;
	constexpr uint16_t SEL3 = 8;
	constexpr uint16_t SEL4 = 12;
	constexpr uint16_t I2C_EN1 = 1;
	constexpr uint16_t I2C_EN2 = 5;
	constexpr uint16_t I2C_EN3 = 9;
	constexpr uint16_t I2C_EN4 = 13;
	constexpr uint16_t EN1 = 3;
	constexpr uint16_t EN2 = 7;
	constexpr uint16_t EN3 = 11;
	constexpr uint16_t EN4 = 15;
	constexpr uint16_t FAULT1 = 2;
	constexpr uint16_t FAULT2 = 6;
	constexpr uint16_t FAULT3 = 10;
	constexpr uint16_t FAULT4 = 14;
}
// const uint8_t TX = 1;
// const uint8_t RX = 0;
// const uint8_t FOut = 1;
// const uint8_t Dir = 0;

//IO Expander pins
const uint8_t POS_DETECT = 12; 
const uint8_t SENSE_EN = 13;

//IO Sense pins
const uint8_t MUX_EN = 3;
const uint8_t MUX_SEL0 = 0;
const uint8_t MUX_SEL1 = 1;
const uint8_t MUX_SEL2 = 2;

const float VoltageDiv = 2; //Program voltage divider
const float CurrentDiv = 0.243902439; //82mOhm, 50V/V Amp

//Configured for pins on the Particle Boron
//const uint8_t EXT_EN = 8;
//const uint8_t SDA_CTRL = 2;

 const uint8_t I2C_EN = 13;

char ReadArray[25] = {0};

 // Adafruit_MCP23008 io;
// Adafruit_MCP23X17 io;
PCAL9535A ioAlpha(0x20);
PCAL9535A ioBeta(0x21);
// MCP2301x io;

// #define IOEXP_MODE  (IOCON_INTCC | IOCON_INTPOL | IOCON_ODR | IOCON_MIRROR)
// #define ADDRESS      (MCP2301X_CTRL_ID+7)
// #define LED_PIN      D4   // WeMOS D1 & D1 mini
// #define IN_PORT      0
// #define OUT_PORT     1

// #define RELAY_ON      LOW
// #define RELAY_OFF     HIGH
// #define ALL_OFF       ALL_LOW

// #define DIR 0x00
// #define GPIO 0x12
// #define LAT 0x14
// #define PU 0x0C
// #define ADR 0x20

//////////////// GPS /////////////////
#include "SparkFun_Ublox_Arduino_Library.h" //http://librarymanager/All#SparkFun_Ublox_GPS
SFE_UBLOX_GPS GPS;

/////////////// VEML3328 //////////////
#include "VEML3328.h"

VEML3328 ALS;

////////////// SHTC3 ////////////////
#include "SHTC3.h" 

SHTC3 RH; //Instatiate RH sensor

///////////// MXC6655 (Accel) ////////////////
#include <math.h>

//////////// MMC5633 (Mag) ////////////////

//////////// CSA ///////////////////
#include <PAC1934.h>
// PAC1934 CSA_Alpha(10, 10, 2, 2, 0x10); //Initalize with R32 = 10m, R34 = 10m, R23 = 2m, R10 = 2m, ADR = 0x10
// PAC1934 CSA_Beta(2, 10, 2, 2, 0x14); //Initalize with R6 = 2m, R15 = 10m, R7 = 2m, R8 = 2m, ADR = 0x11

PAC1934 CSA_Alpha(2, 2, 2, 2, 0x18); //Initalize with R32 = 10m, R34 = 10m, R23 = 2m, R10 = 2m, ADR = 0x10
PAC1934 CSA_Beta(2, 10, 10, 10, 0x14); //Initalize with R6 = 2m, R15 = 10m, R7 = 2m, R8 = 2m, ADR = 0x14

/////////// SD /////////////////
#include <SdFat.h>
#include <SPI.h>
SdFat SD;
char FileNameC[11]; //Used for file handling
boolean SD_Init = false;

/////////// FRAM /////////////

/////////// RTC /////////////
#include "MCP7940.h" //FIX! Update
MCP7940 Clock; // Instantiate Clock


//////////// LED ////////////
#include <PCA9634.h>

PCA9634 led(0x52); //Instatiate LED driver with 0x50 address

/////////////// SDI-12 Talon //////////////////////
//Input Pins
#include <MCP3221.h>
MCP3221 apogeeADC;
const uint8_t TX_SDI12 = 9;
const uint8_t RX_SDI12 = 10;

//IO Expander Pins
const uint8_t FOut = 14;
const uint8_t Dir = 15;

PCAL9535A ioTalonSDI12(0x25);

#define MARKING_PERIOD 9 //>8.33ms for standard marking period
const unsigned long TimeoutStandard = 380; //Standard timeout period for most commands is 380ms 

/////////////// AUX Talon //////////////////////
#include <Adafruit_ADS1015.h>

Adafruit_ADS1115 ads(0x49); 

PCAL9535A ioAUXAlpha(0x20);
PCAL9535A ioAUXBeta(0x23);
PCAL9535A ioAUXGamma(0x24);

//IO Expander Pins - ALPHA
const uint8_t REG_EN = 7;
const uint8_t ADC_INT = 12;
const uint8_t RST = 6;

const uint8_t EN1 = 1;
const uint8_t FAULT1 = 0;

//IO Expander Pins - BETA
const uint8_t LOAD = 6;
const uint8_t OUT1 = 0;
const uint8_t COUNT_EN1 = 3;
const uint8_t OVF1 = 7;
const uint8_t D1_SENSE = 10;
const uint8_t OD1 = 13;



// const uint8_t MUX_EN = 11;
// const uint8_t MUX_SEL2 = 10;
// const uint8_t MUX_SEL1 = 9;
// const uint8_t MUX_SEL0 = 8;

/////////////// HAAR (Sensor1) ////////////////////// 
#include <Dps368.h>
#include <Adafruit_SHT31.h>
#include <SparkFun_PCA9536_Arduino_Library.h>
#include <MCP3421.h>
#include <SparkFun_SCD30_Arduino_Library.h>
#include <Adafruit_SGP30.h>


PCAL9535A ioTalonI2C(0x22);

MCP3421 adcSense(0x6B); //Initialize MCP3421 with A3 address

PCA9536 ioSense;

Dps368 pressureSenseA = Dps368(); //Instantiate DPS368 Pressure sensor
Adafruit_SHT31 rhSenseA = Adafruit_SHT31(); //Instantiate the SHT31 RH/Temp sensor

Dps368 pressureSenseB = Dps368(); //Instantiate DPS368 Pressure sensor
Adafruit_SHT31 rhSenseB = Adafruit_SHT31(); //Instantiate the SHT31 RH/Temp sensor

SCD30 airSensor; //Instatiate SCD30 CO2 sensor
Adafruit_SGP30 sgp; //Instantiate SGP30 Gas Sensor

const uint8_t dps368_oversampling = 7; //Define the oversampling amount for the DPS368 sensor
unsigned long period = 5000; //Number of ms to wait between sensor readings 



SYSTEM_MODE(MANUAL);
// SYSTEM_MODE(AUTOMATIC); //DEBUG!

void setup() 
{
	// I2C_OnBoardEn(false); //DEBUG!
	// pinMode(TX_SDI12, OUTPUT); //DEBUG!
	// Serial1.begin(1200, SERIAL_8N1); //DEBUG!
	// I2C_OnBoardEn(false); //DEBUG!
	// Serial1.begin(1200, SERIAL_FLOW_CONTROL_NONE); //DEBUG!
	
	pinMode(Pins::WD_HOLD, OUTPUT); //Make sure WDT is configured 
	digitalWrite(Pins::WD_HOLD, LOW); 
	Cellular.setActiveSim(INTERNAL_SIM);
	// Cellular.setCredentials("vzwinternet"); // Replace with the correct APN
	Cellular.setCredentials(""); // Go back to base APN
	const uint8_t val = 0x01;
	dct_write_app_data(&val, DCT_SETUP_DONE_OFFSET, 1);
	// pinMode(I2C_EN, OUTPUT); 
	// digitalWrite(I2C_EN, HIGH); //Turn on external port connection
	Serial.begin(115200);
	

	I2C_OnBoardEn(true); //RESTORE
	// Wire.setClock(10000); //DEBUG!
	Wire.setClock(400000); //Confirm operation in fast mode
	Wire.begin();
	// pinSetDriveStrength(D0, DriveStrength::HIGH);
	// pinSetDriveStrength(D1, DriveStrength::HIGH);
	ioAlpha.begin(); //RESTORE
	ioBeta.begin(); //RESTORE
	// bma456.initialize();
	// ioAlpha.pinMode(PinsIOAlpha::CE, OUTPUT);
	// ioAlpha.digitalWrite(PinsIOAlpha::CE, HIGH); //DEBUG! Turn off charging 

	SetDefaultPins();
	// SetPinMode();
	// SetPullups();
	// io.digitalWrite(6, HIGH); //Turn on 5V
	// io.digitalWrite(7, HIGH); //Turn on 12V
	// io.digitalWrite(2, LOW); //Enable Data 1
	// io.digitalWrite(3, LOW); //Enable Data 2
	// io.digitalWrite(4, LOW); //Enable Data 3

	pinMode(TX_SDI12, OUTPUT); //DEBUG1!
	// ioTalonSDI12.pinMode( Dir, OUTPUT); //Set to output 
	// ioTalonSDI12.pinMode( FOut, OUTPUT); //Set to output 
	// ioTalonSDI12.digitalWrite( Dir, HIGH); //Set to transmit 
//  io.digitalWrite( FOut, LOW); //DEBUG!
	// Serial1.begin(1200, SERIAL_7E1);
	// Serial1.begin(115200); //High speed serial test
	Serial1.begin(1200, SERIAL_8N1);
	delay(1000);
	Serial.println("Begin I2C Demo...");
}

void loop() 
{
	// io.pinMode(0, TX, LOW);
	// io.pinMode(0, FOut, LOW);
	// delay(1000);
	// io.pinMode(0, FOut, LOW);
	// io.pinMode(0, TX, HIGH);
	// delay(1000);
	// io.pinMode(0, FOut, HIGH);
	// io.pinMode(0, TX, LOW);
	// delay(1000);
	// io.pinMode(0, FOut, HIGH);
	// io.pinMode(0, TX, HIGH);
	// delay(1000);
	static int ReadLength = 0;
  	String ReadString;
	if(Serial.available() > 0) {
    char Input = Serial.read();

    // Increment counter while waiting for carrage return or newline
    // if(Input != 13 || Input != 10) {
    if(Input != '#' && Input != '!' && Input != '*') { //Wait for control, data, or SDI-12 line end
      ReadArray[ReadLength] = Input;
      ReadLength++;
    }

    // if(Input == 13 || Input == 10) { // carriage or newline
    if(Input == '!') { //Command line ending
		// ReadArray[ReadLength] = Input; //Append final character
		// ReadLength++;

		// ReadString = String(ReadArray);
		// ReadString.trim();
		// memset(ReadArray, 0, sizeof(ReadArray));
		// ReadLength = 0;
		// // int Pin = (ReadString.substring(0,1)).toInt(); //Grab the pin to operate on

		// Serial.print(">");
		// Serial.println(ReadString); //Echo back to serial monitor

		// switch(Pin) { //Call the interface function for the appropriate sensor to test
		// 	case 0:
		// 		VoltageSense();
		// 		break;
		// 	case 1:
		// 		Sensor1();
		// 		break;
		// 	case 2:
		// 		Sensor2();
		// 		break;
		// 	case 3:
		// 		Sensor3();
		// 		break;
		// 	case 4:
		// 		Sensor4();
		// 		break;
		// 	default:
		// 		Serial.println(">You didn't say the magic word!"); 
		// }

		ReadArray[ReadLength] = Input; //Append final character
		ReadLength++;

		ReadString = String(ReadArray);
		ReadString.trim();
		memset(ReadArray, 0, sizeof(ReadArray));
		ReadLength = 0;

		// while(Serial.peek() != '\n'); //Wait for new command
		// String NewCommand = Serial.readStringUntil('\n');
		Serial.print(">");
		Serial.println(ReadString); //Echo back to serial monitor
		Serial.println(SendCommand(ReadString));
		
	}

	if(Input == '*') {
		ReadString = String(ReadArray);
		ReadString.trim();
		memset(ReadArray, 0, sizeof(ReadArray));
		ReadLength = 0;

		Serial.print(">");
		Serial.println(ReadString); //Echo back to serial monitor

		if(ReadString.equalsIgnoreCase("Cell")) {
			TestCell(); //Connect to network and test cell status
		}

		if(ReadString.equalsIgnoreCase("GPS")) {
			TestGPS(); //Call GPS test
		}

		if(ReadString.equalsIgnoreCase("GPSTime")) {
			GetGPSTime(); //Grab current GPS time
		}

		if(ReadString.equalsIgnoreCase("ALS")) {
			TestALS(); //Call ALS test
		}

		if(ReadString.equalsIgnoreCase("Atmos")) {
			TestAtmos(); //Call Temp/pressure/RH test
		}

		if(ReadString.equalsIgnoreCase("Accel")) {
			TestAccel(); //Call Accelerometer test
		}

		if(ReadString.equalsIgnoreCase("Mag")) {
			TestMag(false, false); //Call Magnetometer test (no offset compensation)
			TestMag(true, false); //Call Magnetometer test SET
			TestMag(false, true); //Call Magnetometer test RESET
		}

		if(ReadString.equalsIgnoreCase("CSA")) {
			TestCSA(); //Call CSA test
		}

		if(ReadString.equalsIgnoreCase("SD")) {
			TestSD(); //Call SD test
		}

		if(ReadString.equalsIgnoreCase("SDRead")) {
			ReadSD(); //Call SD test
		}

		if(ReadString.equalsIgnoreCase("FRAM")) {
			TestFRAM(false, false); //Call FRAM test
		}

		if(ReadString.equalsIgnoreCase("FRAMRead")) {
			TestFRAM(true, false); //Read the last FRAM write location
		}

		if(ReadString.equalsIgnoreCase("FRAMReadAll")) {
			TestFRAM(false, true); //Dump all FRAM data, Serial Bomb Incoming...
		}

		if(ReadString.equalsIgnoreCase("RTC")) {
			TestRTC(false, false); //Call RTC test
			//Include EEPROM??
		}

		if(ReadString.equalsIgnoreCase("RTCRead")) {
			TestRTC(true, false); //Read the last RTC EEPROM/SRAM data
			//Include EEPROM??
		}

		if(ReadString.equalsIgnoreCase("RTCReadAll")) {
			TestRTC(false, true); //Dump all EEPROM/SRAM data, Serial Bomb Incoming...
			//Include EEPROM??
		}


		if(ReadString.equalsIgnoreCase("Time")) {
			ReadRTC(); //Call RTC read only
			//Include EEPROM??
		}

		if(ReadString.equalsIgnoreCase("LED")) {
			TestLED(); //Call LED test
		}

		if(ReadString.equalsIgnoreCase("Battery")) {
			TestBattery(); //Read battery state from Gonk 
		}

		if(ReadString.equalsIgnoreCase("USB")) {
			TestUSB(); //Run USB test 
		}

		if(ReadString.equalsIgnoreCase("I2C")) {
			TestI2C(); //Run I2C scan 
		}

		if(ReadString.equalsIgnoreCase("Sensor1")) {
			SensorDemo1(); //Run sensor 1 demo  
		}

		if(ReadString.equalsIgnoreCase("Sensor2")) {
			SensorDemo2(); //Run sensor 2 demo  
		}

		if(ReadString.equalsIgnoreCase("Sensor3")) {
			SensorDemo3(); //Run sensor 3 demo  
		}

		if(ReadString.equalsIgnoreCase("TalonEEPROM")) {
			TalonEEPROMTest(); //Run test for EEPROM on Talon
		}

		if(ReadString.equalsIgnoreCase("TalonEEPROMRead")) {
			TalonEEPROMRead(); //Run test for EEPROM on Talon
		}

		if(ReadString.equalsIgnoreCase("PortTest")) {
			PortTest(); //Run custom port test
		}

	}
	//Format (reduced) - ppCs#
	//pp - two digit pin number (base 10)
	//C - command ('M' - Mode, 'R' - Read, 'W' - Write)
	//s - state (0 - Output/Off, 1 - Input/On), required only for write and mode operations 

	//Format (extended) - DppCs#
	//D - device you wish to address ('A' - I/O Exp Alpha, 'B' - I/O Exp Beta, 'D' - Default aka Controller)
	//pp - two digit pin number (base 10)
	//C - command ('M' - Mode, 'R' - Read, 'W' - Write)
	//s - state (0 - Output/Off, 1 - Input/On), required only for write and mode operations 
	if(Input == '#') { //Control line ending
		ReadString = String(ReadArray);
		ReadString.trim();
		memset(ReadArray, 0, sizeof(ReadArray));
		ReadLength = 0;
		int Pin = 0;
		int State = 0;
		int Result = 0; //Used to grab result of either setting of pin mode or response from a read
		char Device = 'D'; //Specify default device 
		if(ReadString.charAt(0) < '0' || ReadString.charAt(0) > '9') { //If first digit is not a number, assume providing extended set 
			Device = ReadString.charAt(0); 
			ReadString.remove(0, 1); //Clear the leading character so it can be read normally 
		}
		Pin = (ReadString.substring(0,2)).toInt(); //Grab the pin to operate on
		String Operation = ReadString.substring(2,3); //Grab the middle char
		State = (ReadString.substring(3,4)).toInt(); //Grab the state to set
		

		// digitalWrite(I2C_EN, LOW); //Turn off external port connection
		if(Operation.equals("M")) { //if call is for pinmode setting
			switch(Device) { 
				case 'D':
					// pinMode(Pin, State); //Use normal state logic 
					if(State == 0) pinMode(Pin, OUTPUT);
          			if(State == 1) pinMode(Pin, INPUT);
          			Result = 0; //Set manually
					break;
				case 'A':
					Result = ioAlpha.pinMode(Pin, !State); //Use inverse of state to corespond with 1 = input, 0 = output
					break;
				case 'B':
					Result = ioBeta.pinMode(Pin, !State); //Use inverse of state to corespond with 1 = input, 0 = output
					break;
			}
		}
		
		if(Operation.equals("R")) { //If call is for digital read
			switch(Device) {
				case 'D':
					Result = digitalRead(Pin); 
					break;
				case 'A':
					Result = ioAlpha.digitalRead(Pin);
					break;
				case 'B':
					Result = ioBeta.digitalRead(Pin);
					break;
			}
		}

		if(Operation.equals("W")) { //If call is for digital write
			switch(Device) {
				case 'D':
					// digitalWrite(Pin, State);
					if(State == 0) digitalWrite(Pin, LOW);
          			if(State == 1) digitalWrite(Pin, HIGH);
					Result = State; //Set manually //DEBUG!
					break;
				case 'A':
					Result = ioAlpha.digitalWrite(Pin, State);
					break;
				case 'B':
					Result = ioBeta.digitalWrite(Pin, State);
					break;
			}
		}

		if(Operation.equals("N")) { //If call is for interrupt read
			switch(Device) {
				case 'D':
					Result = -1; //throw error 
					break;
				case 'A':
					Result = ioAlpha.getInterrupt(Pin);
					break;
				case 'B':
					Result = ioBeta.getInterrupt(Pin);
					break;
			}
		}
		// digitalWrite(I2C_EN, HIGH); //Turn on external port connection
		// while(Serial.peek() != '\n'); //Wait for new command
		// String NewCommand = Serial.readStringUntil('\n');
		Serial.print(">");
		Serial.println(ReadString); //Echo back to serial monitor
		Serial.print(">");
		Serial.println(Result); //Return various result 
	}
	// GetAddress();
	// delay(5000);

	}
}

// void VoltageSense() //Voltage sense (AKA Sensor0)
// {
// 	Serial.print(">Voltage Sense:\n");
// 	digitalWrite(I2C_EN, LOW); //Turn off external I2C
// 	io.digitalWrite(SENSE_EN, HIGH); //Make sure sense power is turned on
// 	ioSense.begin(); //Initalize voltage sensor IO expander
// 	for(int i = 0; i < 4; i++) { //Set all pins to output
// 		ioSense.pinMode(i, OUTPUT); 
// 	}
// 	ioSense.digitalWrite(MUX_EN, HIGH); //Turn MUX on 
// 	int SenseError = adc.Begin(); //Initialize ADC 
// 	if(SenseError == 0) { //Only proceed if ADC connects correctly
// 		adc.SetResolution(18); //Set to max resolution (we paid for it right?) 

// 		ioSense.digitalWrite(MUX_SEL2, LOW); //Read voltages
// 		for(int i = 0; i < 4; i++){ //Increment through 4 voltages
// 			ioSense.digitalWrite(MUX_SEL0, i & 0b01); //Set with lower bit
// 			ioSense.digitalWrite(MUX_SEL1, (i & 0b10) >> 1); //Set with high bit
// 			delay(1); //Wait for voltage to stabilize
// 	  		Serial.print("\tPort");
// 	  		Serial.print(i);
// 	  		Serial.print(":");
// 	  		Serial.print(adc.GetVoltage(true)*VoltageDiv, 6); //Print high resolution voltage
// 	  		Serial.print(" V\n");  
// 		}
// 		ioSense.digitalWrite(MUX_SEL2, HIGH); //Read currents
// 		for(int i = 0; i < 4; i++){ //Increment through 4 voltages
// 			ioSense.digitalWrite(MUX_SEL0, i & 0b01); //Set with lower bit
// 			ioSense.digitalWrite(MUX_SEL1, (i & 0b10) >> 1); //Set with high bit
// 			delay(1); //Wait for voltage to stabilize
// 	  		Serial.print("\tPort");
// 	  		Serial.print(i);
// 	  		Serial.print(":");
// 	  		Serial.print(adc.GetVoltage(true)*CurrentDiv*1000, 6); //Print high resolution current measure in mA
// 	  		Serial.print(" mA\n");  
// 		}
// 	}
// 	else Serial.print("\tFAIL!\n");
// 	digitalWrite(I2C_EN, HIGH); //Turn on external I2C
// }


// void Sensor1() 
// {
// 	// Serial.println(">Spector1");
// 	/////////////// SETUP /////////////////////
// 	uint8_t error_dps368 = 0; //DEBUG! FIX! Change library to return stuff properly
// 	pressureSense.begin(Wire); //Initialize DPS368 sensor //DEBUG! FIX! Change library to return stuff properly
// 	uint8_t error_sht31 = rhSense.begin(0x44); //Initialize SHT31 sensor
	
// 	Serial.println(">Haar Status:"); //Print resulting sensor status 
// 	Serial.print("\tDPS368: "); 
// 	if(error_dps368 == 0) Serial.print("PASS\n"); //Print error grabbed from sensor
// 	else Serial.print("FAIL!\n"); //Fail if result is not 0
// 	Serial.print("\tSHT31: ");
// 	if(error_sht31 == 1) Serial.print("PASS\n"); //Print error grabbed from sensor
// 	else Serial.print("FAIL!\n"); //Fail if result is 0

// 	///////////////// RUN ////////////////////
// 	float temp_dps368; //Storage for temp measurement from DPS368 
//   	float pressure; //Storage for pressure measurment from DPS368
  	

// 	int16_t error1 = pressureSense.measureTempOnce(temp_dps368, dps368_oversampling); //Grab new temp values [°C]
// 	int16_t error2 = pressureSense.measurePressureOnce(pressure, dps368_oversampling); //Grab new pressure values [Pa]
// 	pressure = pressure/100.0f; //Convert from Pa to mBar, because Pa is a stupid unit, and hPa is more stupid. 

// 	float humidity = rhSense.readHumidity(); //Grab new humidity values [%]
// 	float temp_sht31 = rhSense.readTemperature(); //Grab new temp values [°C]

// 	Serial.print("\tTemp (SHT31): "); Serial.print(temp_sht31, 4); Serial.print(" °C\t"); //Print temp to 4 decimal places
// 	Serial.print("Temp (DPS368): "); Serial.print(temp_dps368, 2); Serial.print(" °C\t"); //Print temp to 2 decimal places
// 	Serial.print("Pressure: "); Serial.print(pressure, 2); Serial.print(" mBar\t"); //Print pressure to 2 decimal places
// 	Serial.print("Humidity: "); Serial.print(humidity, 2); Serial.print(" %\n"); //Print humidity to 2 decimal places
// }

// void Sensor2() 
// {
// 	// Serial.println(">Spector2");
// 	Wire.begin();

// 	Serial.println(">Hedorah Status:");
// 	Serial.print("\tSCD30: ");
// 	if (airSensor.begin() == false)
// 	{
// 		Serial.print("FAIL!\n");
// 	}
// 	else {
// 		Serial.print("PASS\n");
// 		Serial.print("\t...");
// 		unsigned long LocalTime = millis();
// 		while(millis() - LocalTime < 10000){
// 			if (airSensor.dataAvailable())
// 			{
// 				Serial.print("\tCO2: "); //Print sensor CO2 reading
// 				Serial.print(airSensor.getCO2());
// 				Serial.print(" PPM\t");

// 				Serial.print("Temp:"); //Print sensor temp
// 				Serial.print(airSensor.getTemperature(), 1);
// 				Serial.print(" °C\t");

// 				Serial.print("RH:"); //Print sensor RH
// 				Serial.print(airSensor.getHumidity(), 1);
// 				Serial.print(" %\n");
// 				break; //Exit while loop
// 			}
// 		}
// 		if(millis() - LocalTime > 10000) Serial.print("\tERROR: Timeout\n"); //Report timeout error if time has elapsed on exit
// 	}

// }

// void Sensor3() 
// {

// }

// void Sensor4() 
// {

// }
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

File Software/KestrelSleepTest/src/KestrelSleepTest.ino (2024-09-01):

/*
 * Project KestrelSleepTest
 * Description:
 * Author:
 * Date:
 */

// #include <MCP23018.h> //Use for <v1.5
#include <PACL9535A.h> //Use for >=v1.5
#include "SparkFun_Ublox_Arduino_Library.h"

SFE_UBLOX_GPS myGPS;
PACL9535A ioAlpha(0x20); //Use for >=v1.5
PACL9535A ioBeta(0x21); //Use for >=v1.5
// MCP23018 ioAlpha(0x20); //Use for <v1.5

const uint8_t RTC_INT = D22; //FIX!
const uint8_t CSA_EN = 14; //FIX!
const uint8_t LED_EN = 13; //FIX!
const uint8_t AUX_EN = 15; //FIX!
// const uint8_t I2C_OB_EN = A6; //FIX!

const uint8_t FRAM_ADR = 0x50; 
const uint8_t ACCEL_ADR = 0x15;

const uint8_t I2C_OB_EN = D21;
const uint8_t I2C_GLOBAL_EN = D23;

SYSTEM_MODE(AUTOMATIC);

void setup() {
  pinMode(I2C_OB_EN, OUTPUT);
  digitalWrite(I2C_OB_EN, HIGH);
  Wire.begin();
  
  ioAlpha.begin();
  ioBeta.begin();
  ioBeta.clearInterrupt(PACL9535A::IntAge::CURRENT);
  ioAlpha.pinMode(12, OUTPUT); //LOW
  ioAlpha.pinMode(11, OUTPUT); //LOW
  ioAlpha.pinMode(10, OUTPUT); //LOW
  ioAlpha.pinMode(9, INPUT); 
  ioAlpha.pinMode(8, INPUT);
  ioAlpha.pinMode(7, INPUT);
  ioAlpha.pinMode(6, INPUT);
  ioAlpha.pinMode(5, INPUT);
  ioAlpha.pinMode(4, INPUT);
  ioAlpha.pinMode(3, INPUT);
  ioAlpha.pinMode(2, INPUT); //DEBUG! Return to INPUT_PULLUP
  ioAlpha.pinMode(1, INPUT);
  ioAlpha.pinMode(0, INPUT);

  ioAlpha.pinMode(CSA_EN, OUTPUT);
  ioAlpha.pinMode(LED_EN, OUTPUT);
  ioAlpha.pinMode(AUX_EN, OUTPUT);
  ioAlpha.digitalWrite(AUX_EN, HIGH); //DEBUG!
  myGPS.begin();

  pinMode(A4, INPUT);
  pinMode(A5, INPUT);

  // pinMode(I2C_OB_EN, OUTPUT);
  // digitalWrite(I2C_OB_EN, HIGH); //Enable onboard communication 
}

void loop() {

  //Clear Clock, config OSC
  Wire.beginTransmission(0x6F);
  Wire.write(0x07);
  Wire.write(0x88); //Turn on EXT OSC, turn off alarms
  Wire.endTransmission();

  Wire.beginTransmission(0x6F);
  Wire.write(0x0D);
  Wire.write(0x88); //Clear ALARM0
  Wire.endTransmission();

  Wire.beginTransmission(0x6F);
  Wire.write(0x14);
  Wire.write(0x88); //Clear ALARM1
  Wire.endTransmission();

  // //Shutdown Accel
	Wire.beginTransmission(ACCEL_ADR);
	Wire.write(0x0D); //Write to control register
	Wire.write(0x01); //Set power down
	Wire.endTransmission();

  //Shutdown FRAM
	Wire.beginTransmission(0xA0);
	Wire.write((FRAM_ADR << 1) | 0x01); //Shift to add "r/w" bit //FIX!
	Wire.endTransmission(false);
	Wire.beginTransmission(0x43);
	Wire.endTransmission();

  //Use for <v1.5
  // Wire.beginTransmission(0x20);
  // Wire.write(0x0A);
  // Wire.write(0b01000000); //Set INT pins to be ORed and driven
  // Wire.endTransmission();

  // Wire.beginTransmission(0x21);
  // Wire.write(0x0A);
  // Wire.write(0b01000000); //Set INT pins to be ORed and driven
  // Wire.endTransmission();

  ioAlpha.digitalWrite(12, LOW);
  ioAlpha.digitalWrite(11, LOW);
  ioAlpha.digitalWrite(10, LOW);
  ioAlpha.digitalWrite(CSA_EN, LOW); //Turn off CSAs
  ioAlpha.digitalWrite(LED_EN, HIGH); //Turn off LEDs for ultra low power
  ioAlpha.digitalWrite(AUX_EN, LOW); //Turn off auxiliary power
  // ioAlpha.digitalWrite(AUX_EN, HIGH); //DEBUG!
  // myGPS.powerOff(60000);

  digitalWrite(I2C_OB_EN, LOW);

  // SystemSleepConfiguration config;
	// 	config.mode(SystemSleepMode::ULTRA_LOW_POWER)
	// 	.gpio(RTC_INT, FALLING);

  SystemSleepConfiguration config;
		config.mode(SystemSleepMode::ULTRA_LOW_POWER)
		.gpio(RTC_INT, FALLING);
    // .gpio(A4, RISING)
    // .gpio(A5, RISING);
		SystemSleepResult result = System.sleep(config);
}

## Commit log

2021-10-01 Continued schematic capture
    Schematic capture and added modules for Talon interface
    [MainLogger.brd, MainLogger.sch]
2021-10-01 Added VELM3328
    [MainLogger.brd, MainLogger.sch]
2021-10-05 Continued layout and schematic updates
    [MainLogger.brd, MainLogger.sch]
2021-10-06 Initial copper layout complete, cleanup and silk required
    [MainLogger.brd, MainLogger.sch]
2021-10-08 Layout and cleanup complete, review required
    Also add test points
    [MainLogger.brd, MainLogger.sch]
2021-10-12 Layout, gerbers, and BoM for v0.0 - sent to fab
    [MainLogger.brd, MainLogger.sch, MainLogger_0v0.csv]
2021-11-23 Added production files for v0.1, v0.2
    [MainLogger_0v1_BoM.csv, MainLogger_0v2_BoM.csv]
2021-11-23 v1.0 Update
    Many fixes, see ECO and Github issues documentation, v1.0 sent to fab
    [MainLogger.brd, MainLogger.sch]
2021-12-09 Added v1.0 BoM
    [MainLogger_1v0_BoM.csv]
2021-12-10 v1.1 Update
    Added SIM card, updated pinouts, fixed switch circuit
    [MainLogger.brd, MainLogger.sch]
2021-12-22 Updated address note and added renumber file
    [MainLogger.sch]
2021-12-22 v1.2 Updates
    Added I2C_AUX buffer, switched SHT31 to SHT41
    [MainLogger.brd, MainLogger.sch]
2021-12-22 Added series resistors for GPIO output
    [MainLogger.brd, MainLogger.sch]
2021-12-22 v1.2 Gerbers generated
2021-12-22 Switched RTC crystal to TCXO
    [MainLogger.brd, MainLogger.sch]
2022-01-05 Added measures, fixed value of R49
    [MainLogger.brd, MainLogger.sch]
2022-01-12 Fixed passive value, added BoM
    [MainLogger.brd, MainLogger.sch, MainLogger_1v2A_BoM.csv]
2022-01-12 Added SleepTest software
    Added sleep test program to test the low power sleep level of the device
2022-01-27 v1.3 Updates
    Reconfigured backup battery charger
    [MainLogger.brd, MainLogger.sch]
2022-03-09 Updated v1.4 for production
    [MainLogger.brd, MainLogger.sch, MainLogger_1v4_BoM.csv]
2022-03-09 Updated C42 part val
    Fixed C42 part value to correctly reflect 47pF value
    [MainLogger.brd, MainLogger.sch, MainLogger_1v4_BoM.csv]
2022-03-09 Updated part value for C32
    Made C32 reflect the correct library part
    [MainLogger.brd, MainLogger.sch, MainLogger_1v4_BoM.csv]
2022-04-25 v1.5 Update
    Updated schematic and layout, boards sent to fab
    [MainLogger.brd, MainLogger.sch]
2022-05-17 Added v1.5 production outputs
    [MainLogger_1v5_BoM_2022-05-04.csv]
2022-06-14 v1.6 Update
    [MainLogger.brd, MainLogger.sch, MainLogger_1v6_BoM_2022-05-27.csv]
2022-12-20 Updated CSV for DNPs
    [MainLogger_1v6_BoM_2022-12-16.csv]
2022-12-20 Added fix for WDT
    [MainLogger.brd, MainLogger.sch]
2023-05-15 Generated production files for v1.7
    [MainLogger_1v7_BoM_2022-12-19.csv]
2023-05-15 v1.8 Updates
    - Changed accel (#1)
    - Fixed backup regulator issue (#16)
    - Fixed TCXO overvoltage issue (#19)
    [MainLogger.brd, MainLogger.sch, MainLogger_1v8_BoM_2023-05-10.csv]
2023-06-16 v1.9 updates
    Added series diode in gps/rtc bat charger to prevent reverse current
    [MainLogger.brd, MainLogger.sch]
2023-06-16 Added production files for v1.9
    [MainLogger_1v9_BoM_2023-06-15.csv]
2023-06-16 Fixed soldermask error
    Fixed error in soldermask on X2SOM packages
    [MainLogger.brd, MainLogger.sch]
2023-06-23 Fixed silkscreen numbering
    [MainLogger.brd]
2023-06-29 Updated `R3` Value
    Changed `R3` to 20k to deal with address conflict
    [MainLogger.brd, MainLogger.sch, MainLogger_1v9_BoM_2023-06-29.csv]

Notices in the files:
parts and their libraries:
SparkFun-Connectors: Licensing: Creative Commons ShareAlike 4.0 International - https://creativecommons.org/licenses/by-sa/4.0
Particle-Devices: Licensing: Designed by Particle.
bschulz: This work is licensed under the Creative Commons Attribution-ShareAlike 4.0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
